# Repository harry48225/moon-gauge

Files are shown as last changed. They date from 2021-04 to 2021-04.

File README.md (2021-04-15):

# moon-gauge 🌔

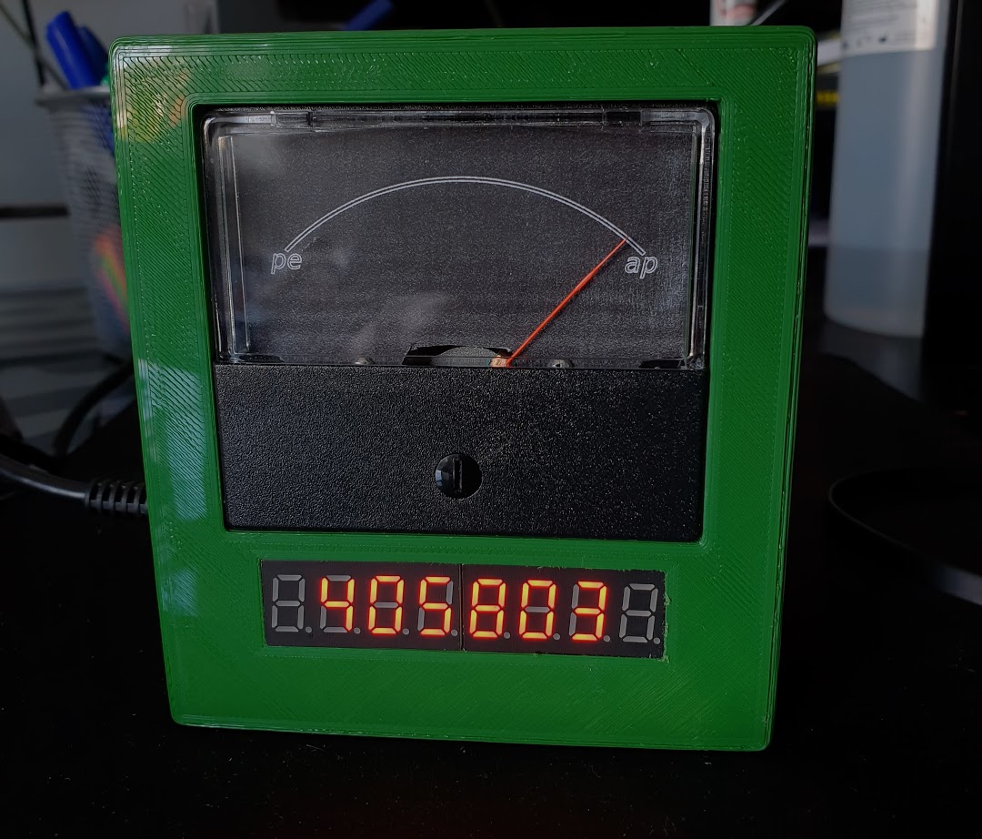
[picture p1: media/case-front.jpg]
the device


## a pi pico powered display of the moon's current distance.

An analog voltmeter is used to show at what stage the moon is at in its orbit (between apogee and perigee) and an 8 digit seven segement display to display the current distance in km.
It implements an algorithm from *Astronomical algorithms by Jean Meeus*.

There is a python implementation of the algorithm and then the actual ardiuno code including a C implementation of the algorithm in `main.ino`

There are stl files for the case in `CAD/` along with an svg to stick over the orginal voltmeter markings. Heat set inserts should be pressed into the main part of the case using M3 screws to screw the back to the case

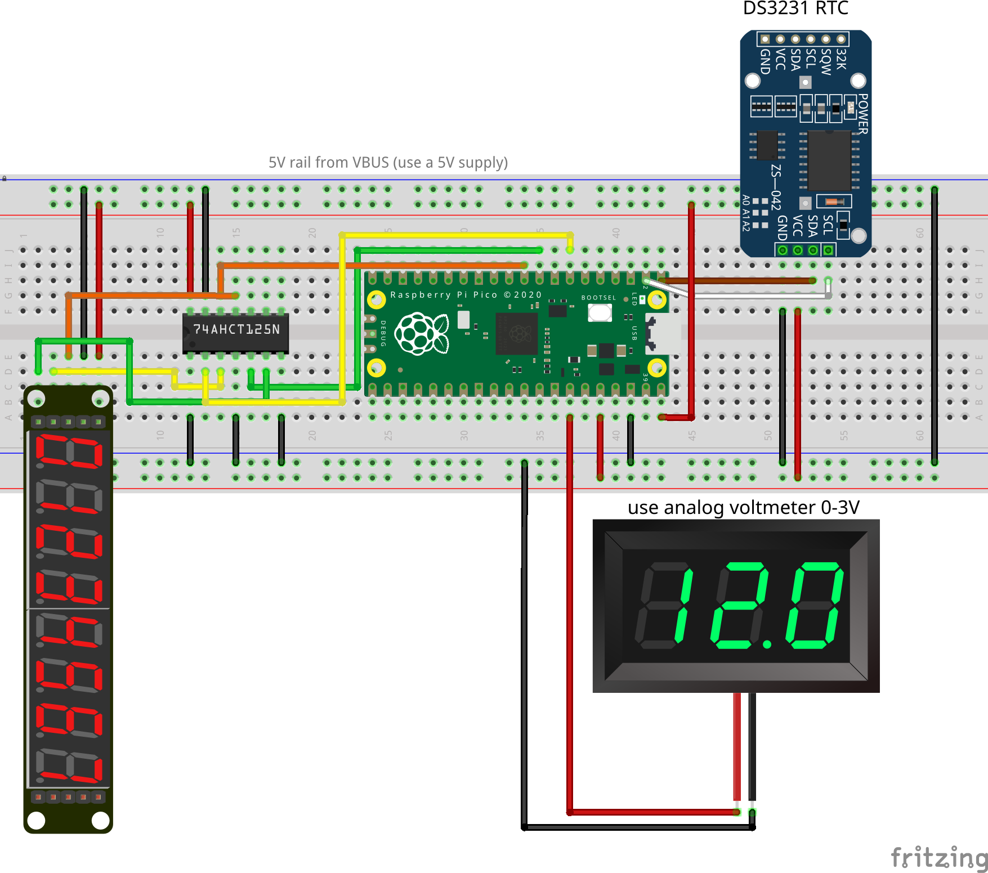
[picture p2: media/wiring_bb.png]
schematic


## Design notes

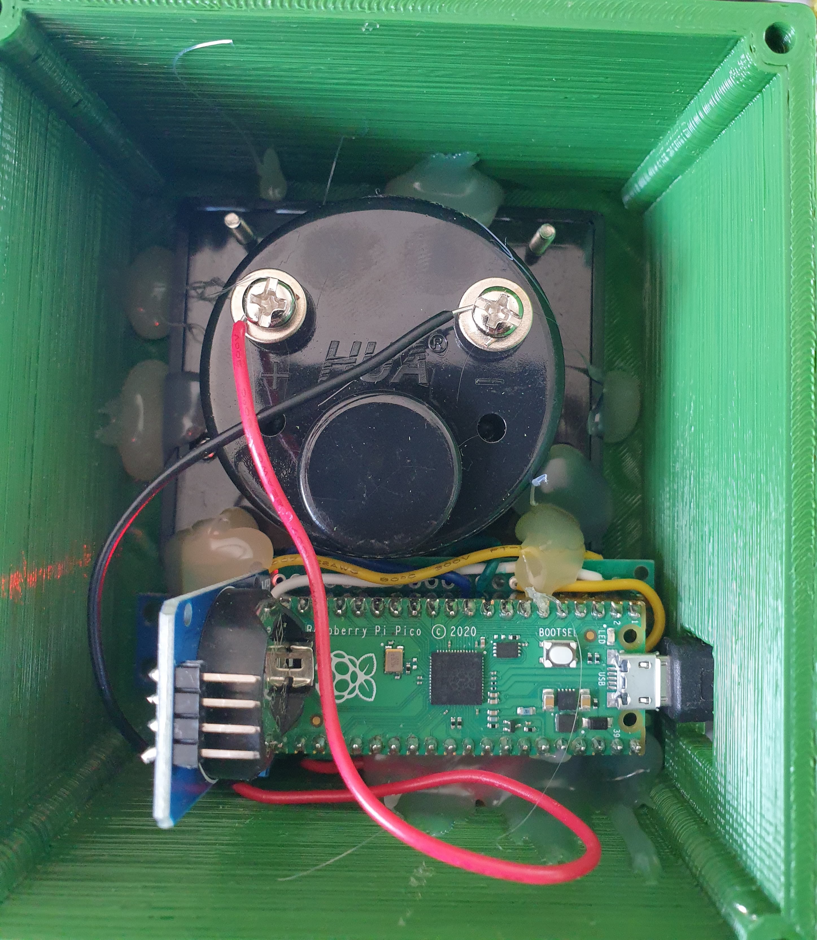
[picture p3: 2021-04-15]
media/internals.jpg

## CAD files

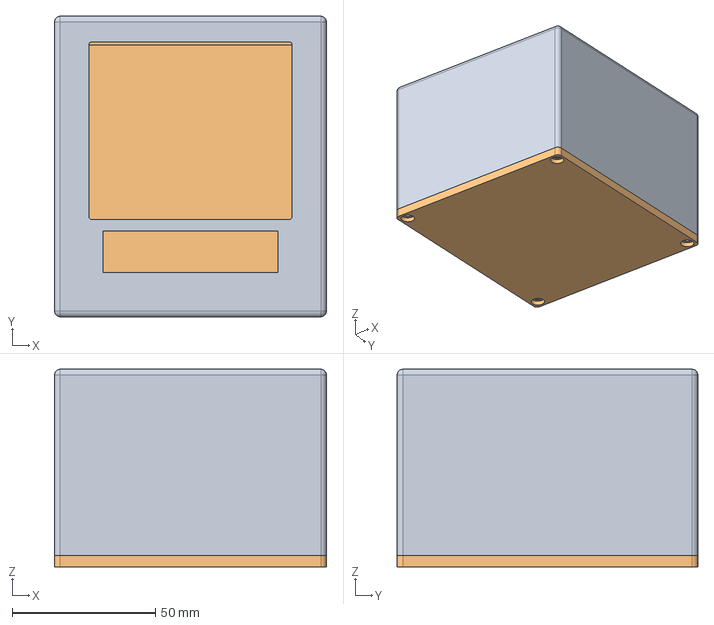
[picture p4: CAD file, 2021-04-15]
CAD/case assembly.FCStd
95.0 x 105.0 x 69.0 mm
case_001
case back_001

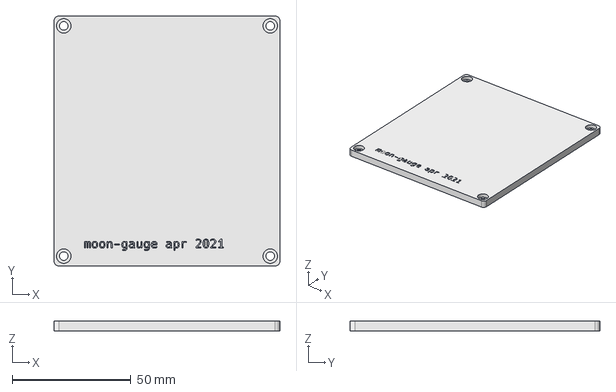
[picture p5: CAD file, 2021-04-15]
CAD/case back.FCStd
95.0 x 105.0 x 4.00 mm

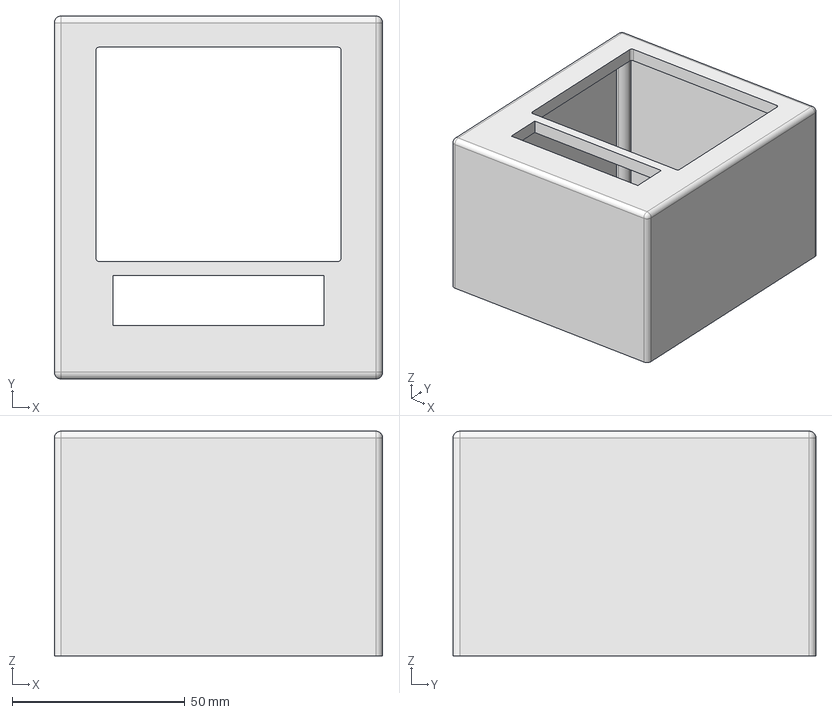
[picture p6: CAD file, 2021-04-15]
CAD/case.FCStd
95.0 x 105.0 x 65.0 mm

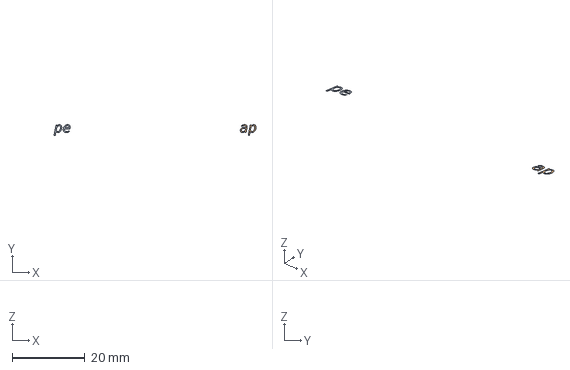
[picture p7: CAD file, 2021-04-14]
CAD/plate graphic.FCStd
55.5 x 2.94 x 0 mm
pe
ap

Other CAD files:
CAD/case-Body.stl
CAD/case back.stl

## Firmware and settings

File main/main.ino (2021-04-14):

//We always have to include the library
#include "LedControl.h"
#include "Wire.h"
#include "DS3231.h"
#include "math.h"

RTClib myRTC;

/*
 Now we need a LedControl to work with.
 ***** These pin numbers will probably not work with your hardware *****
 pin 7 is connected to the DataIn 
 pin 6 is connected to the CLK 
 pin 5 is connected to LOAD 
 We have only a single MAX72XX.
 */
LedControl lc=LedControl(7,6,5,1);

int VOLTMETER_PIN = 28;

/* we always wait a bit between updates of the display */
unsigned long delaytime=250;


/* 
  ---------------------------------------------------------------------
  Moon calculations - taken from  Astronomical algorithms by Jean Meeus 
  ---------------------------------------------------------------------
*/

/* constants */
int D_coefficients [] = {0, 2, 2, 0, 0, 0, 2, 2, 2, 2, 0, 1, 0, 2, 0, 0, 4, 0, 4, 2, 2, 1, 1, 2, 2, 4, 2, 0, 2, 2, 1, 2, 0, 0, 2, 2, 2, 4, 0, 3, 2, 4, 0, 2, 2, 2, 4, 0, 4, 1, 2, 0, 1, 3, 4, 2, 0, 1, 2, 2};
int M_coefficients [] = {0, 0, 0, 0, 1, 0, 0, -1, 0, -1, 1, 0, 1, 0, 0, 0, 0, 0, 0, 1, 1, 0, 1, -1, 0, 0, 0, 1, 0, -1, 0, -2, 1, 2, -2, 0, 0, -1, 0, 0, 1, -1, 2, 2, 1, -1, 0, 0, -1, 0, 1, 0, 1, 0, 0, -1, 2, 1, 0, 0};
int M_prime_coefficients [] = {1, -1, 0, 2, 0, 0, -2, -1, 1, 0, -1, 0, 1, 0, 1, 1, -1, 3, -2, 1, 0, -1, 0, 1, 2, 0, -3, -2, -1, -2, 1, 0, 2, 0, -1, 1, 0, -1, 2, -1, 1, -2, -1, -1, -2, 0, 1, 4, 0, -2, 0, 2, 1, -2, -3, 2, 1, -1, 3, -1};
int F_coefficients [] = {0, 0, 0, 0, 0, 2, 0, 0, 0, 0, 0, 0, 0, -2, 2, -2, 0, 0, 0, 0, 0, 0, 0, 0, 0, 0, 0, 0, 2, 0, 0, 0, 0, 0, 0, -2, 2, 0, 2, 0, 0, 0, 0, 0, 0, -2, 0, 0, 0, 0, -2, -2, 0, 0, 0, 0, 0, 0, 0, -2};
int cos_coefficients [] = {-20905355, -3699111, -2955968, -569925, 48888, -3149, 246158, -152138, -170733, -204586, -129620, 108743, 104755, 10321, 0, 79661, -34782, -23210, -21636, 24208, 30824, -8379, -16675, -12831, -10445, -11650, 14403, -7003, 0, 10056, 6322, -9884, 5751, 0, -4950, 4130, 0, -3958, 0, 3258, 2616, -1897, -2117, 2354, 0, 0, -1423, -1117, -1571, -1739, 0, -4421, 0, 0, 0, 0, 1165, 0, 0, 8752};
int coefficient_length = 60;
double reduce_angle(double angle) {
  /* reduces the angle to be in [0, 360)*/

  return angle - 360 * floor(angle / 360);
}


double find_T_since_julian_epoch(double seconds_since_epoch) {
  return (seconds_since_epoch - 946727936)/((double) 60*60*24*36525);
}

double find_D(double T) {
  /* calculates the mean elongation of the Moon */
  double D = 297.8501921 + 445267.1114034*T - 0.0018819*pow(T,2) + pow(T,3)/545868 - pow(T,4)/113065000;
  return reduce_angle(D);
}

double find_M(double T) {
  /* calculates the Sun's mean anomaly */
  double M = 357.5291092 + 35999.0502909*T - 0.0001536*pow(T,2) + pow(T,3)/24490000;
  return reduce_angle(M);
}

double find_M_prime(double T) {
  /* calculates the Moon's mean anomaly */
  double M_prime = 134.9633964 + 477198.8675055*T + 0.0087414*pow(T,2) + pow(T,3)/69699 - pow(T,4)/14712000;
  return reduce_angle(M_prime);
}

double find_F(double T) {
  /* calculates the moon's argument of latitude (mean distance of the moon from its ascending node) */
  double F = 93.2720950 + 483202.0175233*T - 0.0036539*pow(T,2) - pow(T,3)/3526000 + pow(T,4)/863310000;
  return reduce_angle(F);
}

double find_E(double T) {
  /* calculates the eccentricity of earth's orbit around the sun correction */
  double E = 1 - 0.002516*T - 0.0000074*pow(T,2);
  return E;
}

double cosine_in_degrees(double angle_in_degrees) {
  /* returns the cosine of an angle given in degrees */

  return cos((angle_in_degrees) * (M_PI / 180.0));
}

long calculate_moon_distance(double seconds_since_epoch) {
  /* returns the distance to the moon in at the given seconds since epoch in km*/
  double T = find_T_since_julian_epoch(seconds_since_epoch);
  Serial.println("---calculations---");
  Serial.println(T,10);
  Serial.println(find_D(T),10);
  Serial.println(find_M(T),10);
  Serial.println(find_M_prime(T),10);
  Serial.println(find_F(T),10);
  Serial.println(find_E(T), 10);
  Serial.println("------");

  double D = find_D(T);
  double M = find_M(T);
  double M_prime = find_M_prime(T);
  double F = find_F(T);
  double E = find_E(T);

  double sum_r = 0;

  for (int i = 0; i < coefficient_length; i++) {
    double new_term = cos_coefficients[i]*cosine_in_degrees(
                                        D_coefficients[i]*D + 
                                        M_coefficients[i]*M + 
                                        M_prime_coefficients[i]*M_prime +
                                        F_coefficients[i]*F);

    //perform the eccentricity correction
    if (M_coefficients[i] == 1 || M_coefficients[i] == -1) { new_term *= E; }
    else if (M_coefficients[i] == 2 || M_coefficients[i] ==  -2) { new_term *= pow(E,2); }

    sum_r += new_term;
  }

  double distance = 385000.56 + sum_r/1000;
  Serial.println(distance);
  return (long) distance;
}

void setup() {
  /*
   The MAX72XX is in power-saving mode on startup,
   we have to do a wakeup call
   */
  lc.shutdown(0,false);
  /* Set the brightness to a low values */
  lc.setIntensity(0,2);
  /* and clear the display */
  lc.clearDisplay(0);
  Serial.begin(9600);
  Wire.begin();

  pinMode(VOLTMETER_PIN, OUTPUT);
}

int current_voltmeter = 0;
void display_on_voltmeter(double current, double minimum, double maximum) {
  /* display a value between min and max on the voltmeter*/

  float multiplier = (current - minimum) / (maximum - minimum);

  // 3/3.3 * 255 = 231.8
  float write_value = 232 * multiplier;
  
  // interpolate between the previous and new value
  for (float i = 0; i <= 4; i++) {
    int interpolated_value = current_voltmeter + (i/4)*(write_value - current_voltmeter);
    delay(100);
    analogWrite(VOLTMETER_PIN, (int) interpolated_value);
    Serial.println(interpolated_value);
  }

  current_voltmeter = write_value;
  
  
}

/*
 * display the 8 least significant whole digits of a given number
 */
void display_long(long number) {
  long head = (((long) number) % 100000000);
  Serial.println(number);
  for (int i = 0; i < 6; i++) {
    lc.setDigit(0,i+1, head%(10),false);
    Serial.println(head%(10));
    head = head / 10;
  }
}

void loop () {
  
    delay(500);
    DateTime now = myRTC.now();
    double unixtime = now.unixtime();
    
    Serial.println(now.unixtime());

    long moon_distance = calculate_moon_distance((double) now.unixtime());
    display_long(moon_distance);
    display_on_voltmeter((double) moon_distance, 356400, 406700);

    
}

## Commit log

2021-03-28 ticking clock voltmeter
2021-04-01 very basic arduino
2021-04-04 added voltmeter display
2021-04-04 added interpolation for voltmeter values
2021-04-04 added anomaly calculation to arduino sketch
2021-04-04 completed arduino algorithm implementation
2021-04-06 added wiring diagram
    [wiring.fzz]
2021-04-12 rough cad
    [case.FCStd]
2021-04-12 revision 1 of case front
    [case.FCStd]
2021-04-13 cable hole
    [case-Body.stl, case.FCStd]
2021-04-13 revision 2
    [case-Body.stl, case.FCStd]
2021-04-14 reduced brightness and constrained voltmeter angle
    [case-Body.stl, case.FCStd]
2021-04-14 created custom gauge graphic
    [plate graphic.FCStd]
2021-04-15 added back of case
    [case assembly.FCStd, case back.FCStd, case back.stl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]
